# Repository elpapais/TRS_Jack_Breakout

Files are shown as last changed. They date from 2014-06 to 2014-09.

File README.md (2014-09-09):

1/4" TRS Jack Breakout
========================================

[TRS Jack Breakout
*TRS Jack Breakout (BOB-13005)*](https://www.sparkfun.com/products/13005)

Breakout board for SparkFun [1/4" Stereo TRS jack](https://www.sparkfun.com/products/11144).  
Makes jack easier to use with breadboards, and labels the connections to cut down on confusion about the normal connections.

Repository Contents
-------------------

* **/Hardware** - All Eagle design files (.brd, .sch, .STL)
* **/Production** - Test bed files and production panel files

License Information
-------------------
The hardware is released under [Creative Commons ShareAlike 4.0 International](https://creativecommons.org/licenses/by-sa/4.0/).
The code is beerware; if you see me (or any other SparkFun employee) at the local, and you've found our code helpful, please buy us a round!

Distributed as-is; no warranty is given.

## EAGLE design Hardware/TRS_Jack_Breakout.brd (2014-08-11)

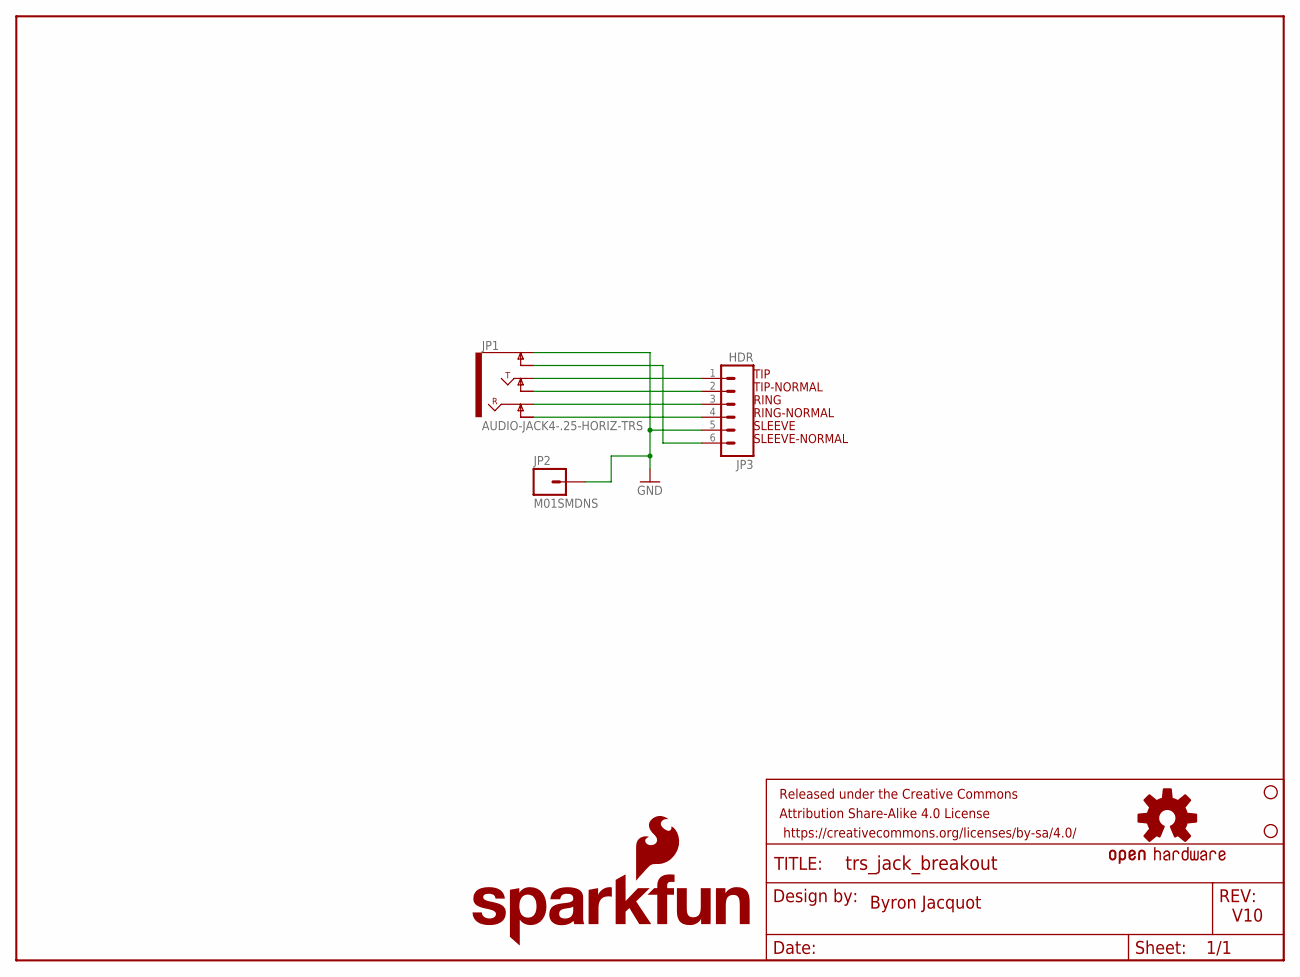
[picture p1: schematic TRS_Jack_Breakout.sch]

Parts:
FRAME1: FRAME-LETTER; CREATIVE_COMMONS
JP1: AUDIO-JACK4-.25-HORIZ-TRS; AUDIO-JACK-.25-INCH-HORIZ-PTH
JP2: M01SMDNS; 1X01NS
JP3: HDR; 1X06_NO_SILK
LOGO1: SFE_LOGO_NAME_FLAME.1_INCH; SFE_LOGO_NAME_FLAME_.1
LOGO2: OSHW-LOGOS; OSHW-LOGO-S
STANDOFF1, STANDOFF2: STAND-OFF

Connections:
GND: JP1.SLEEVE (EARTH), JP2.1, JP3.5
unnamed: JP1.TIP, JP3.1
unnamed: JP1.TIP-NORM, JP3.2
unnamed: JP1.RING, JP3.3
unnamed: JP1.RING-NORM, JP3.4
unnamed: JP1.SLEEVE-NORM (EARTH-NORM), JP3.6

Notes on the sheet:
Byron Jacquot
V10
TIP
TIP-NORMAL
RING
RING-NORMAL
SLEEVE
SLEEVE-NORMAL

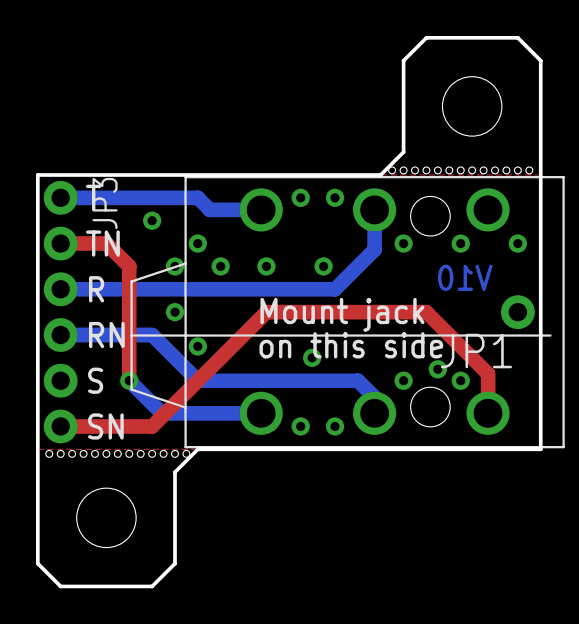
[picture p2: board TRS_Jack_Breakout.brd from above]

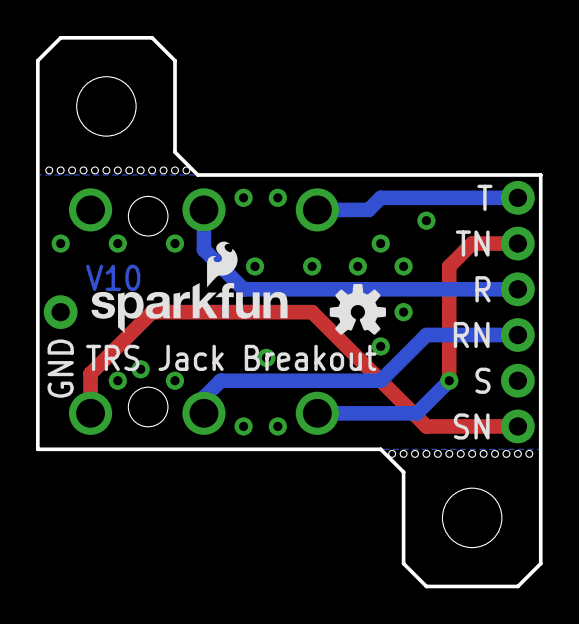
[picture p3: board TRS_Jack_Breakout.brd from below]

Board: 2 copper layers, 27.9 x 30.5 mm, 8 parts (2 on the bottom side), 6 nets.

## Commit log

2014-06-24 Initial board & schem files
    [breakout.brd, breakout.sch]
2014-06-30 Adding mounting holes on tabls, gnd pin
    [TRS_Jack_Breakout.brd, TRS_Jack_Breakout.sch]
2014-07-14 Updating TRS jack footprint
    Drawing in datasheet isn't totally correct. The orientation bosses are
    not actually in line with the connections.
    [TRS_Jack_Breakout.brd, TRS_Jack_Breakout.sch]
2014-08-05 Updating footprint based on protos
    [TRS_Jack_Breakout.brd, TRS_Jack_Breakout.sch]
2014-08-05 Rethinking the rethink on the footprint.
    Got to looking closes at several jacks from stock - they're not very
    consistent, so bosses have been adapted to fit all of them.
    [TRS_Jack_Breakout.brd, TRS_Jack_Breakout.sch]
2014-08-11 Updates after red review.
    Wider outline on dimension layer, added gear logo.
    [TRS_Jack_Breakout.brd, TRS_Jack_Breakout.sch]

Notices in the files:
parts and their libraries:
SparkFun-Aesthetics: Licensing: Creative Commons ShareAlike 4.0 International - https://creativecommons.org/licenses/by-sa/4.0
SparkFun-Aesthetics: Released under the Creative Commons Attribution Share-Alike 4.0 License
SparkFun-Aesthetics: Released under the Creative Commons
